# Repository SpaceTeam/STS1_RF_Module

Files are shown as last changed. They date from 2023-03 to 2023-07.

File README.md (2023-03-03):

# STS1 RF Module

This PCB is the RF subsystem of the STS1 COBC ("Communication and On Board Computer") isolated on a separate PCB to test the RF subsystem.  
The complete RF path was simulated using QUCS (see [the STS1_RF_Simulations repo](https://github.com/SpaceTeam/STS1_RF_Simulations) for the files).

It is based around the Si4463 RF IC and features an LNA, 2W power amplifier and filtering built for our CubeSat and is designed for a frequency around 435MHz.

Feel free to use this for whatever you want but there are two important things to consider:
- 2W is way more than legal without some form of license in most countries so make sure that whatever you are planning to do is legal in your country.
- The filtering and matching is designed for 435MHz. For any other frequency you'll probably go into the QUCS project and find suitable values for your frequency.
  - The matching of the Si4463 is described in [AN643](https://www.silabs.com/documents/public/application-notes/AN643.pdf) and [AN648](https://www.silabs.com/documents/public/application-notes/AN648.pdf)
  - The matching of the PA and LNA is done using the [QUCS matching network calculation tool](https://qucs-help.readthedocs.io/en/0.0.19/matching.html)
  - The low pass filters most likely can stay the same if you don't drastically change the frequency
  - The band pass filters are stolen from [ORESAT0 C3](https://github.com/oresat/oresat-c3/) so you'll have to figure this out on your own :P
- When using this in space, you'll want to add some form of watchdog to the `TX_Block` input and latch-up protection for at least the 3.3V rail (the power amplifier has it's own e-fuse on the 5V rail)

## Current state

### v1.0

Currently untested!  
The TX path excluding the RF switch were mostly tested before but the rest is untested.

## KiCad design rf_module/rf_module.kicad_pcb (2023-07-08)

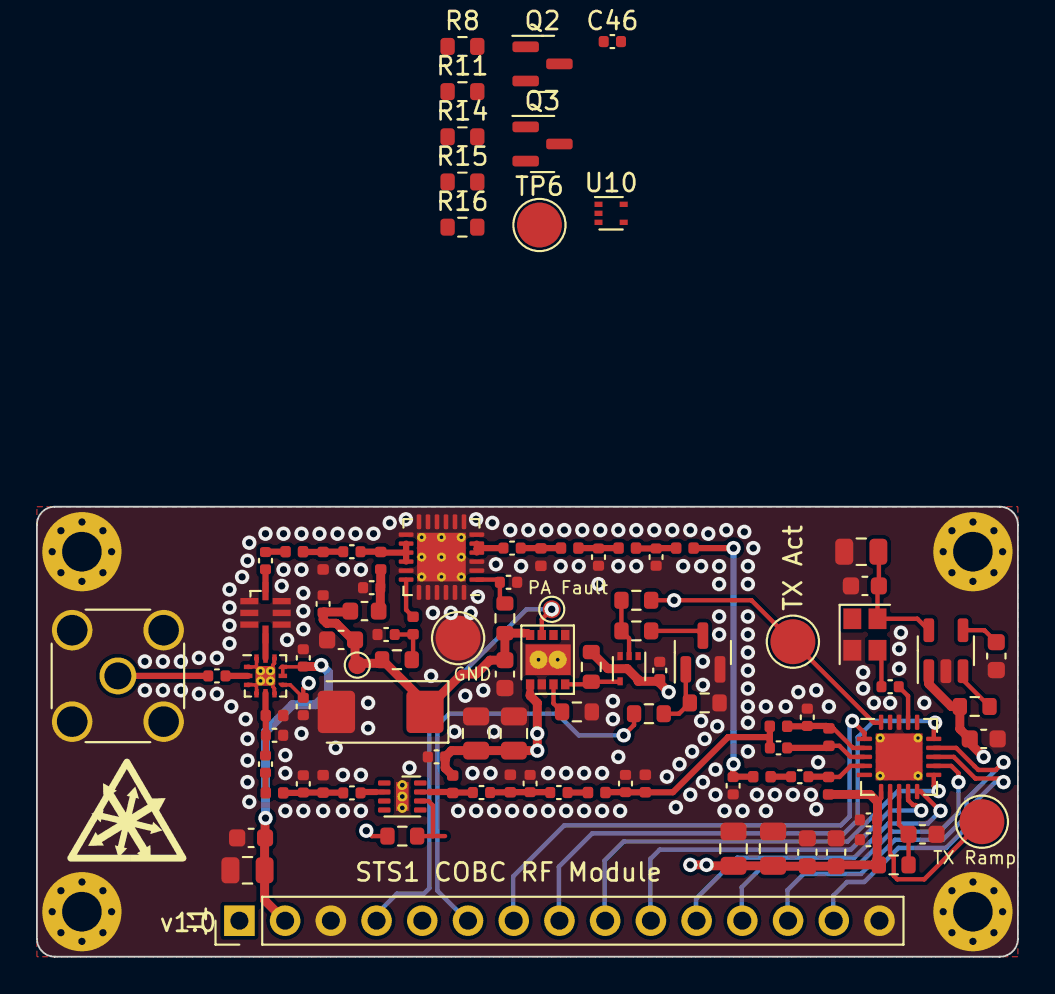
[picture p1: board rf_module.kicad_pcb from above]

Board: 4 copper layers, 54.5 x 25.0 mm, 107 parts (0 on the bottom side), 63 nets.

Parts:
C1, C6, C15, C23, C33, C39: 100n; C_0603_1608Metric
C2, C4: 7.5p; C_0402_1005Metric
C3, C21: 10n; C_0603_1608Metric
C5, C25: 4.7µ; C_0805_2012Metric
C7, C11, C24, C29, C44: 24p; C_0402_1005Metric
C8, C9, C12, C14, C18, C19, C30, C31, C32, C36, C42, C43, C46: 100p; C_0402_1005Metric
C10, C28: 2p; C_0402_1005Metric
C13: 1u; C_0805_2012Metric
C16: 33p; C_0402_1005Metric
C17: 9.1p; C_0402_1005Metric
C20: 4.7p; C_0402_1005Metric
C22: 2.2p; C_0402_1005Metric
C26: 15p; C_0402_1005Metric
C27: 47µ; C_0805_2012Metric
C34: 1µ; C_0805_2012Metric
C35: 100n; C_0402_1005Metric
C37: 50p; C_0402_1005Metric
C38: 10u; C_0805_2012Metric
C40: 10u; CP_EIA-6032-28_Kemet-C
C41: 1n; C_0603_1608Metric
C45: 3.3p; C_0402_1005Metric
FB1: Ferrite_Bead; L_0603_1608Metric
H1, H2, H3, H4: MH; MountingHole_2.2mm_M2_Pad_Via
J1: Conn_01x15; PinHeader_1x15_P2.54mm_Vertical
J2: UHF; SMA_Amphenol_132134_Vertical
L1, L3, L12: 33n; L_0402_1005Metric
L2: 51n; L_0402_1005Metric
L4, L6, L11, L14: 5.6n; L_0402_1005Metric
L5, L7, L13, L15: 68n; L_0402_1005Metric
L8: 220n; L_0402_1005Metric
L9: 62n; L_0402_1005Metric
L10: 56n; L_0402_1005Metric
L16: 4n; L_0402_1005Metric
L17: 18n; L_0402_1005Metric
L18: 8.2n; L_0402_1005Metric
L19: 47n; L_0402_1005Metric
Q1, Q2, Q3: SQ2318; SOT-23
R1, R12: 100k; R_0603_1608Metric
R2, R5, R8, R11, R16: 100; R_0603_1608Metric
R3, R4, R14, R15: 10k; R_0603_1608Metric
R6: 4.7; R_0603_1608Metric
R7: 33k; R_0603_1608Metric
R9: 240; R_0603_1608Metric
R10: 280; R_0603_1608Metric
R13: 110k; R_0603_1608Metric
TP1: TXRAMP; TestPoint_Pad_D2.5mm
TP2: TX_Active; TestPoint_Pad_D2.5mm
TP3: GND; TestPoint_Pad_D2.5mm
TP4: PA_Fault; TestPoint_Pad_D1.0mm
TP5: 5V_PA; TestPoint_Pad_D1.0mm
TP6: RX_Active; TestPoint_Pad_D2.5mm
U1: LP2985-1.8; SOT-23-5
U2: TYKTBCSANF-26.000000; Crystal_SMD_2520-4Pin_2.5x2.0mm
U3, U10: NL17SV04XV5T2G; SOT-553
U4: Si4463; QFN-20-1EP_4x4mm_P0.5mm_EP2.6x2.6mm_ThermalVias
U5: TQP3M9036; DFN-8-1EP_2x2mm_P0.5mm_EP0.7x1.6mm_ThermalVias
U6: LFCG-490+; GE0805C-2
U7: F2972; IDT_NEG-12-1EP_2x2mm_P0.5mm_EP1.1x1.1mm_ThermalVias
U8: FPF2701; MLP-8
U9: TQP7M9106; QFN-24-1EP_4x4mm_P0.5mm_EP2.7x2.7mm_ThermalVias

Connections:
+3V3: C1.1, C8.2, C16.1, C19.1, C21.1, C23.1, C25.1, C27.1, C31.1, C33.1, C34.1, C46.1, J1.2, L8.2, R1.1, R6.2, R12.2, U1.1 (VIN), U3.5 (VCC), U4.6 (VDD), U7.8 (EN), U7.9 (VCC), U10.5 (VCC)
+5V: C13.1, C14.1, C38.1, J1.1, L7.2, U8.1 (VIN)
/3V3_Si_Filt: C15.1, R6.1, U4.8 (VDD)
/PA_Block: J1.6, R2.1
/PA_Enable: J1.5, R16.1
/PA_Fault: J1.4, TP4.1, U8.7 (FLAGB)
/RF_BPF1_Mid: C28.1, L13.2
/RF_BPF1_Out: C18.2, C24.1, L11.2, L13.1
/RF_BPF2_In: C10.2, C11.1, C12.1, L6.2
/RF_BPF2_Mid: C10.1, L5.2
/RF_BPF2_Out: C7.1, C22.2, L4.2, L5.1, L10.2
/RF_Connector: C32.2, J2.1 (In)
/RF_LNA_In: C18.1, U5.2 (RFIN)
/RF_LNA_Out: C12.2, L7.1, U5.7 (RFOUT)
/RF_LPF1_In: C26.1, L1.1, L12.2
/RF_LPF1_Mid1: C2.1, L1.2, L2.1
/RF_LPF1_Mid2: C4.1, L2.2, L3.1
/RF_LPF1_Out: C37.1, L3.2, L16.2
/RF_LPF2_In: C45.2, U6.8 (IN)
/RF_Si_Inn: C22.1, L9.2, U4.3 (RXn)
/RF_Si_Inp: C20.1, L9.1, L10.1, U4.2 (RXp)
/RF_Si_Match: C17.2, L12.1
/RF_Si_Out: C17.1, L8.1, U4.4 (TX)
/RF_Sw: C32.1, U7.2 (RFC)
/RF_Sw1: C28.2, C29.1, L14.2, U7.5 (RF1)
/RF_Sw2: U6.4 (OUT), U7.11 (RF2)
/RX_Active: TP6.1, U4.19 (GPIO2), U10.2
/Si4463_GPIO0: J1.10, U4.9 (GPIO0)
/Si4463_GPIO1: J1.11, U4.10 (GPIO1)
/Si4463_SDI: J1.13, U4.14 (SDI)
/Si4463_SDN: J1.7, U4.1 (SDN)
/Si4463_SDO: J1.14, U4.13 (SDO)
/Si4463_SPI_CLK: J1.12, U4.12 (SCLK)
/Si4463_nIRQ: J1.9, U4.11 (~IRQ)
/Si4463_nSEL: J1.8, U4.15 (~SEL)
/TX_Active: C30.1, R4.1, TP2.1, U4.20 (GPIO3), U7.7 (Vctl)
/UHF_PA/5V_TX_Filt: C43.2, FB1.1, L17.1
/UHF_PA/5V_TX_U: C39.1, C40.1, C41.1, C42.1, FB1.2, R9.1, R10.2, TP5.1, U8.8 (VOUT)
/UHF_PA/RF_Amp_In: C37.2, U9.4 (RFIN), U9.5 (RFIN)
/UHF_PA/RF_Amp_Match1: C44.2, L18.1, L19.1
/UHF_PA/RF_Amp_Match2: C45.1, L19.2
/UHF_PA/RF_Amp_Out: C44.1, L17.2, U9.14 (RFOUT/VCC), U9.15 (RFOUT/VCC), U9.16 (RFOUT/VCC)
/UHF_PA/~PA_EN: R12.1, U3.4, U8.4 (ON)
GND: C1.2, C2.2, C3.2, C4.2, C5.2, C6.2, C7.2, C8.1, C11.2, C13.2, C14.2, C15.2, C16.2, C19.2, C20.2, C21.2, C23.2, C24.2, C25.2, C26.2, C27.2, C29.2, C30.2, C31.2, C33.2, C34.2, C35.2, C36.2, C38.2, C39.2, C40.2, C41.2, C42.2, C43.1, C46.2, H1.1, H2.1, H3.1, H4.1, J1.3, J1.15, J2.2 (Ext), L4.1, L6.1, L11.1, L14.1, L16.1, L18.2, Q1.2 (S), Q2.2 (S), Q3.2 (S), R3.1, R13.2, R14.1, R15.1, TP3.1, U1.2 (GND), U2.2 (GND), U3.3 (GND), U4.18 (GND), U4.21 (GND), U5.9 (GND), U6.1 (GND), U6.2 (GND), U6.3 (GND), U6.5 (GND), U6.6 (GND), U6.7 (GND), U7.1 (GND), U7.3 (GND), U7.4 (GND), U7.6 (GND), U7.10 (GND), U7.12 (GND), U7.13 (GND), U8.2 (PGOOD), U8.5 (GND), U8.9 (GND), U9.2 (GND), U9.3 (GND), U9.6 (GND), U9.7 (GND), U9.8 (GND), U9.9 (GND), U9.10 (GND), U9.11 (GND), U9.12 (GND), U9.13 (GND), U9.17 (GND), U9.19 (GND), U9.20 (GND), U9.21 (GND), U9.22 (GND), U9.23 (GND), U9.24 (GND), U9.25 (EP), U10.3 (GND)
unnamed: C35.1, L15.2, R9.2
unnamed: Q1.3 (D), R5.1
unnamed: Q1.1 (G), R2.2, R3.2
unnamed: Q2.3 (D), R8.1
unnamed: Q2.1 (G), R11.2, R14.2
unnamed: Q3.3 (D), R11.1
unnamed: Q3.1 (G), R15.2, R16.2
unnamed: R4.2, R5.2, R8.2, U3.2
unnamed: R7.2, U10.4
unnamed: C3.1, U1.4 (BP)
unnamed: R1.2, U1.3 (ON/~OFF)
unnamed: C5.1, C6.1, U1.5 (VOUT), U2.4 (VDD)
unnamed: C9.1, U2.3 (OUT)
unnamed: TP1.1, U4.7 (TXRAMP)
unnamed: C9.2, U4.17 (XIN)
unnamed: R7.1, U5.6 (Shut_Down)
unnamed: R13.1, U8.3 (ISET)
unnamed: L15.1, U9.18 (IREF)
unnamed: C36.1, R10.1, U9.1 (VBIAS)

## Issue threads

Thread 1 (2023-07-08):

power amp supply inductor current rating

XDjackieXD, 2023-07-08:
current inductor has too low rating

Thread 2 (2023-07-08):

5V better filter

XDjackieXD, 2023-07-08:
currently ~2Vpp of RF pass through the VCC filter back into the power supply which is too much

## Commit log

2023-03-02 feat: Schematic done
    [rf_module.kicad_pcb, rf_module.kicad_sch, uhf_pa.kicad_sch]
2023-03-03 feat: minor schematic adjustments and pcb layout
    [rf_module.kicad_pcb, rf_module.kicad_sch, uhf_pa.kicad_sch]
2023-03-03 fix: DRC
    [rf_module.kicad_pcb]
2023-03-03 feat: add current status of v1.0 to readme
2023-05-24 feat: implement LNA activation on RX and PA_Enable in schematic (layout TODO)
    [rf_module.kicad_pcb, rf_module.kicad_sch, uhf_pa.kicad_sch]
2023-07-08 fix: component values of TX PA input matching and filter
    [rf_module.kicad_pcb, rf_module.kicad_sch, uhf_pa.kicad_sch]
